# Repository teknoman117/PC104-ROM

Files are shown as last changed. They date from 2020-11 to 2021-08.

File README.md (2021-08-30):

# PC104-ROM

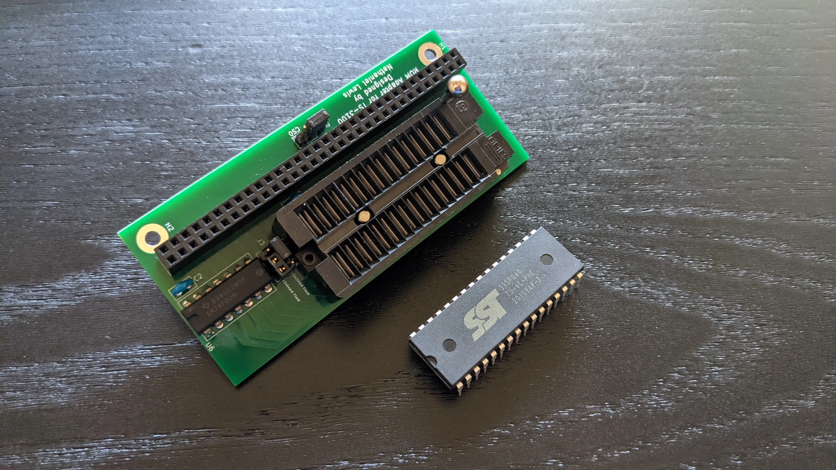
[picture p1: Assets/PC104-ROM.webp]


A carrier board for a 32 pin JEDEC ROM device. Used to override the internal ROM of the Technologic Systems TS-3100.

The TS-3100 does not have a compliant PC/104 connector, as the DMA pins are replaced with some internal signals. This board takes advantage of that by allowing an external ROM to be selected from some of these signals.

Licensed under CC-BY-SA 4.0

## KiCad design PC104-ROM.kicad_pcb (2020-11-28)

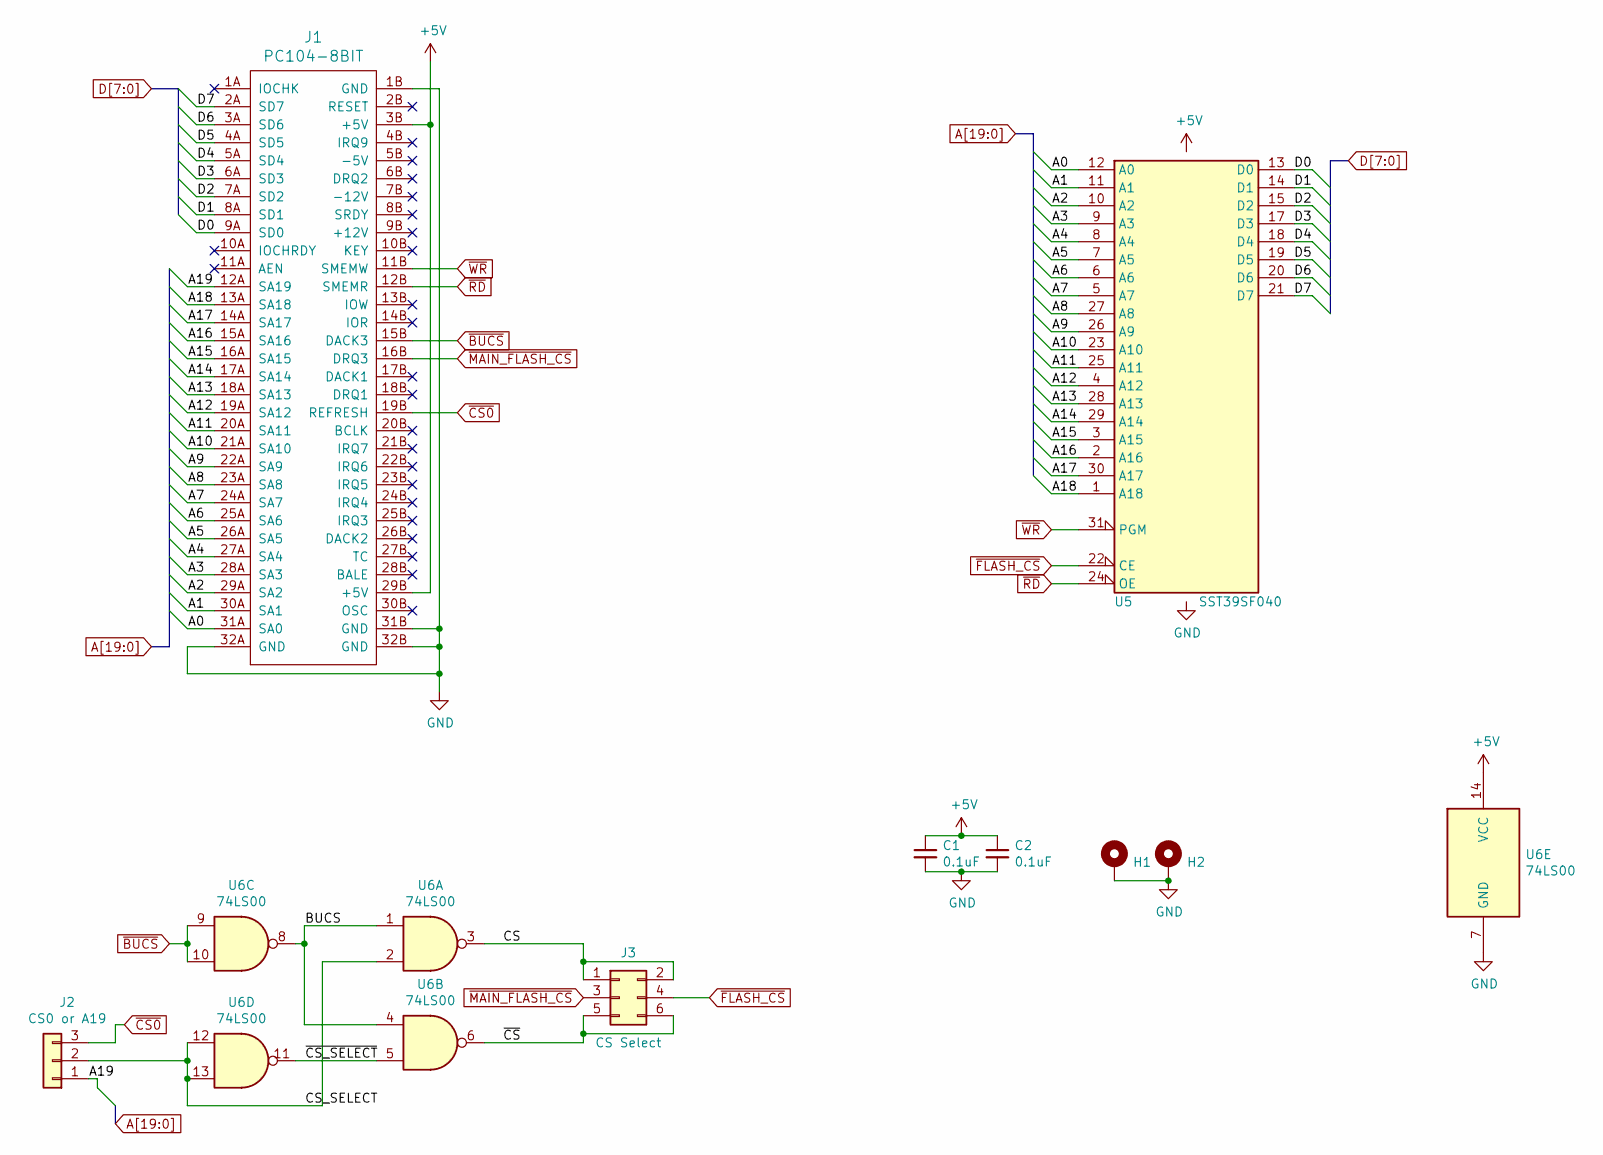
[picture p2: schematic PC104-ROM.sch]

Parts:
C1, C2: 0.1uF; C_Disc_D5.0mm_W2.5mm_P2.50mm
H1, H2: MountingHole_3.2mm_M3_Pad
J1: PC104-8BIT; PC104-8bit
J2: CS0 or A19; PinHeader_1x03_P2.54mm_Vertical
J3: CS Select; PinHeader_2x03_P2.54mm_Vertical
U5: SST39SF040; DIP-32_W15.24mm_Socket
U6: 74LS00; DIP-14_W7.62mm_Socket

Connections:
+5V: C1.1, C2.1, J1.3B (+5V), J1.29B (+5V), U5.32 (VCC), U6.14 (VCC)
/A0: J1.31A (SA0), U5.12 (A0)
/A1: J1.30A (SA1), U5.11 (A1)
/A2: J1.29A (SA2), U5.10 (A2)
/A3: J1.28A (SA3), U5.9 (A3)
/A4: J1.27A (SA4), U5.8 (A4)
/A5: J1.26A (SA5), U5.7 (A5)
/A6: J1.25A (SA6), U5.6 (A6)
/A7: J1.24A (SA7), U5.5 (A7)
/A8: J1.23A (SA8), U5.27 (A8)
/A9: J1.22A (SA9), U5.26 (A9)
/A10: J1.21A (SA10), U5.23 (A10)
/A11: J1.20A (SA11), U5.25 (A11)
/A12: J1.19A (SA12), U5.4 (A12)
/A13: J1.18A (SA13), U5.28 (A13)
/A14: J1.17A (SA14), U5.29 (A14)
/A15: J1.16A (SA15), U5.3 (A15)
/A16: J1.15A (SA16), U5.2 (A16)
/A17: J1.14A (SA17), U5.30 (A17)
/A18: J1.13A (SA18), U5.1 (A18)
/A19: J1.12A (SA19), J2.1
/BUCS: U6.1, U6.4, U6.8
/CS: J3.1, J3.2, U6.3
/CS_SELECT: J2.2, U6.2, U6.12, U6.13
/D0: J1.9A (SD0), U5.13 (D0)
/D1: J1.8A (SD1), U5.14 (D1)
/D2: J1.7A (SD2), U5.15 (D2)
/D3: J1.6A (SD3), U5.17 (D3)
/D4: J1.5A (SD4), U5.18 (D4)
/D5: J1.4A (SD5), U5.19 (D5)
/D6: J1.3A (SD6), U5.20 (D6)
/D7: J1.2A (SD7), U5.21 (D7)
/~CS: J3.5, J3.6, U6.6
/~CS_SELECT: U6.5, U6.11
GND: C1.2, C2.2, H1.1, H2.1, J1.1B (GND), J1.31B (GND), J1.32A (GND), J1.32B (GND), U5.16 (GND), U6.7 (GND)
~BUCS: J1.15B (DACK3), U6.9, U6.10
~CS0: J1.19B (REFRESH), J2.3
~FLASH_CS: J3.4, U5.22 (CE)
~MAIN_FLASH_CS: J1.16B (DRQ3), J3.3
~RD: J1.12B (SMEMR), U5.24 (OE)
~WR: J1.11B (SMEMW), U5.31 (PGM)

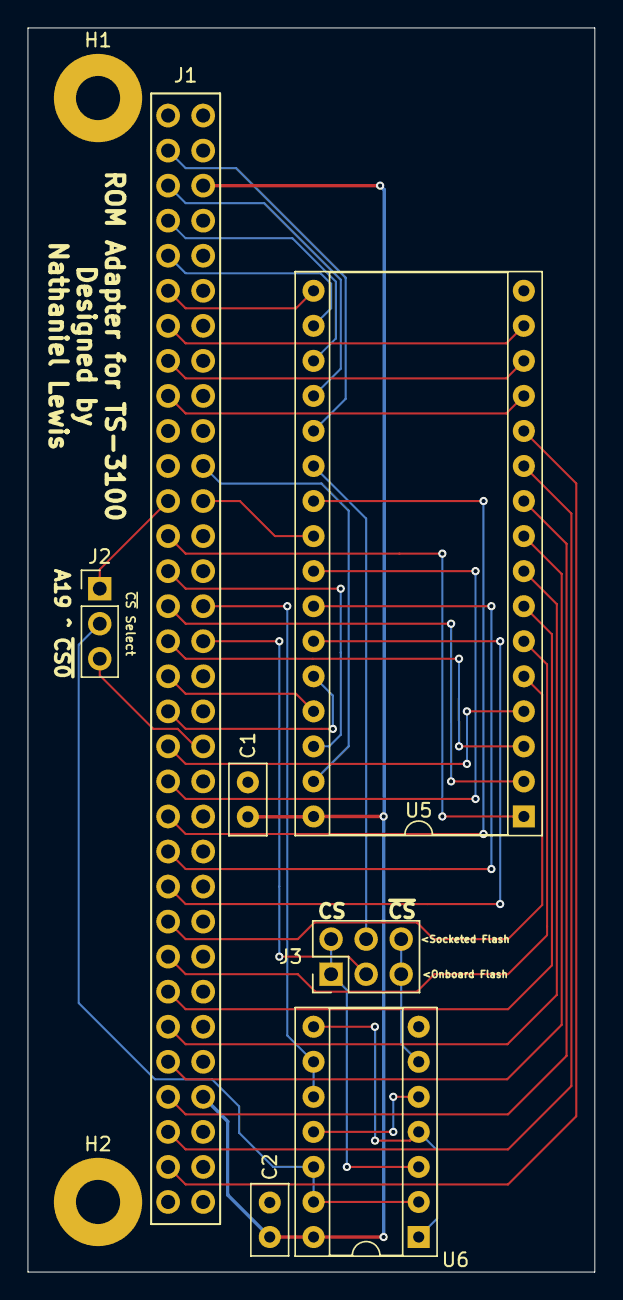
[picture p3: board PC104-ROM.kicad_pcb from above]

Board: 2 copper layers, 41.1 x 90.2 mm, 9 parts (0 on the bottom side), 41 nets.

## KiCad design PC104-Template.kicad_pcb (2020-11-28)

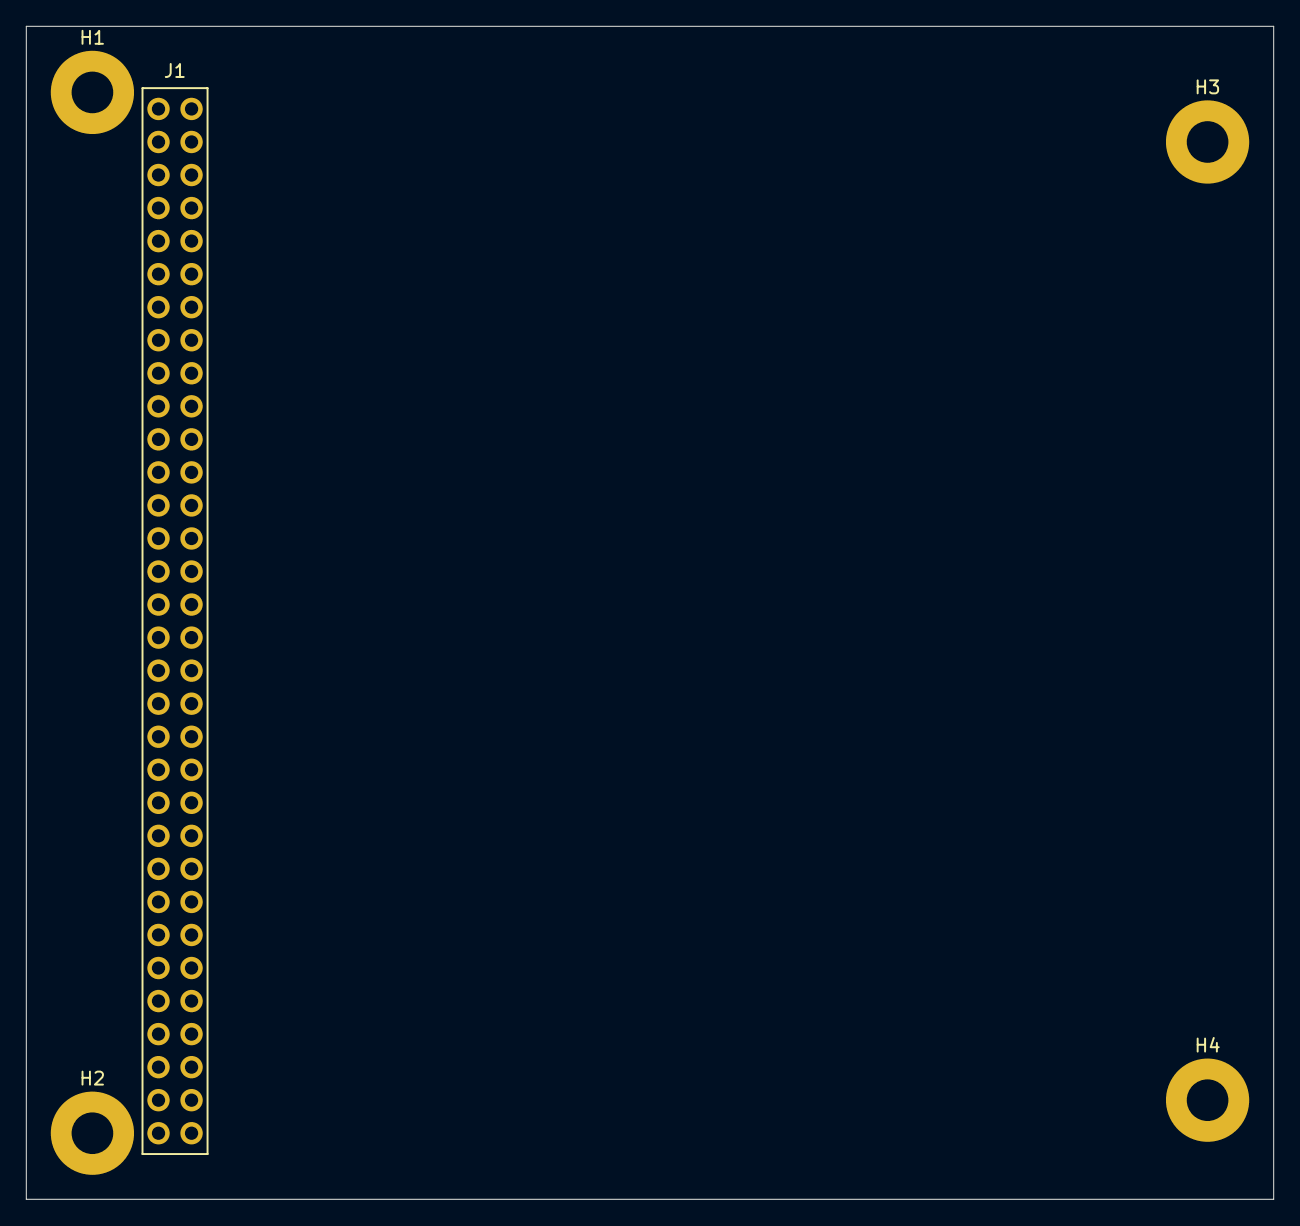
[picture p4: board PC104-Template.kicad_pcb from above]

Board: 2 copper layers, 95.9 x 90.2 mm, 5 parts (0 on the bottom side), 2 nets, no tracks yet.

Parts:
H1, H2, H3, H4: MountingHole_3.2mm_M3_Pad
J1: PC104-8BIT; PC104-8bit

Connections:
+5V: J1.3B, J1.29B
GND: H1.1, H2.1, H3.1, H4.1, J1.1B, J1.31B, J1.32A, J1.32B

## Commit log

2020-11-28 add KiCad-Lib
2021-08-30 add gerber files for revision 1.0
    [PC104-ROM-B_Cu.gbl, PC104-ROM-B_Mask.gbs, PC104-ROM-B_SilkS.gbo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]
